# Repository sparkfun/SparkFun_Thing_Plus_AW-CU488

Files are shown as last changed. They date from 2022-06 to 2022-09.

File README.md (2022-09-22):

SparkFun AzureWave Thing Plus (AW-CU488)
========================================

SparkFun AzureWave Thing Plus (AW-CU488) (https://www.sparkfun.com/products/19957)

[*SparkFun AzureWave Thing Plus (AW-CU488) (DEV-19957)*](https://www.sparkfun.com/products/19957)

The SparkFun AzureWave Thing Plus is a Feather form-factor development board equipped with the AW-CU488. The module features the Realtek RTL8721DM integrated single-chip low-power dual-band (2.4GHz and 5GHz) wireless LAN <!--and Bluetooth&reg; Low Energy (V5.0) --> communication controller. It also consists of a dual processor core: Real-M300 CPU (ARMv8-M, Cortex-M33) and Real-M200 CPU (ARMv8-M, Cortex-M23). Connect the SparkFun AzureWave Thing Plus to the cloud to grab current weather conditions in your area, post sensor data to a server, control the lights in your next home automation project, or even calculate the Fast Fourier Transform (FFT) of an input audio signal!

Why the name? We lovingly call it the “Thing” because it's perfect for your Internet of Things project. The Thing does everything from turning on an LED to posting data with your chosen platform and can be programmed just like any microcontroller. You can even program the Thing through the Arduino IDE by installing the [Realtek Arduino core](https://github.com/ambiot/ambd_arduino). 

The board includes a USB-C connector for programming and power. Two buttons for reset and boot are also populated on the board. For those that need to go remote with their application, the board includes a 2-pin JST connector and the MCP73831 single cell, LiPo charge IC (set to a default rate of 500mA). Voltage is regulated down for the AW-CU488 with the XC6222 3.3V/700mA voltage regulator. Three status LEDs are available for power, charging, and status. Due to the size of the module, the board is slightly longer than the standard Thing Plus footprint. With the added length, we were able to break out a few more PTHs on the edge of the board for a total of 30 GPIO pins (30 Interrupts, seven Analog, 11 PWM, two UARTs, two SPI, and a single I<sup>2</sup>C). The board also includes a built-in audio CODEC with two channel analog inputs and outputs at various sample rates (8/12/16/24/32/48/.../176.4 kHz). On the back of the board are five jumpers for the LiPo charge rate, LED, auto boot circuit, and USB shielding. Finally, one Qwiic connector is populated on the board to easily add Qwiic-enabled I<sup>2</sup>C devices to your projects! 

Repository Contents
-------------------

* **/Documentation** - Datasheets, additional product information
* **/Hardware** - Eagle design files (.brd, .sch)
  * **/Production** - Production panel files (.brd)

Documentation
--------------

* **[Board Definitions](https://github.com/ambiot/ambd_arduino)** - Arduino board support files for the SparkFun AzureWave Thing Plus (AW-CU488)
* **[Hookup Guide](https://learn.sparkfun.com/tutorials/2518)** - Basic hookup guide

Product Versions
----------------

* [DEV-19957](https://www.sparkfun.com/products/19957) - Initial release

Version History
---------------
* v1.0 - Initial release

License Information
-------------------

This product is _**open source**_! 

Please review the LICENSE.md file for license information. 

If you have any questions or concerns on licensing, please contact technical support on our [SparkFun forums](https://forum.sparkfun.com/viewforum.php?f=152).

Distributed as-is; no warranty is given.

- Your friends at SparkFun.

_<COLLABORATION CREDIT>_

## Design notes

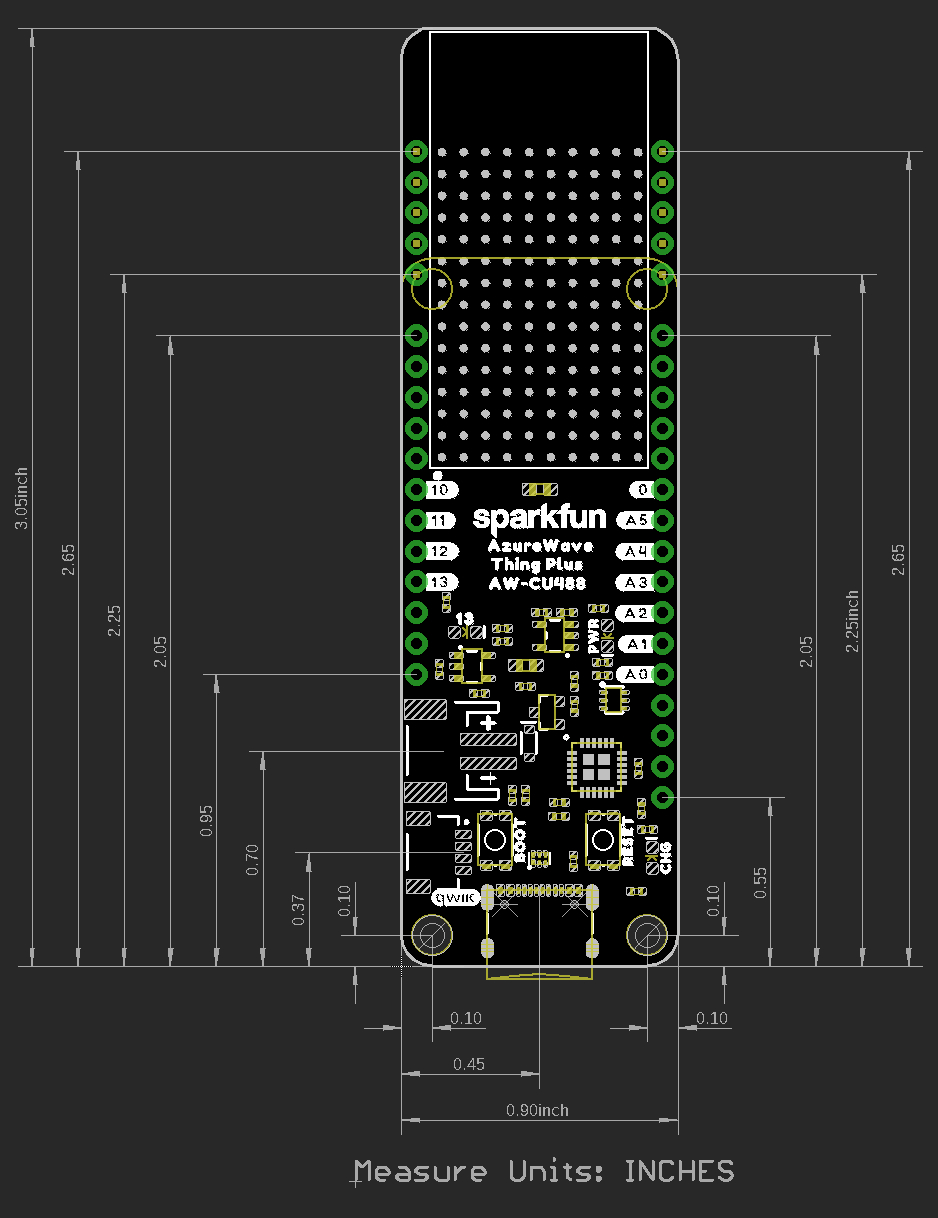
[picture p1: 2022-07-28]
Documents/SparkFun_ThingPlus_AW-CU488_DIMENSIONAL_DRAWINGS.jpg

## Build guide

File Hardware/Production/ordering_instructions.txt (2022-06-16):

panel size, 131x187mm
PCB thickness, 1.6mm
number of layers, 4
soldermask color, Red
silkscreen color, White
oz copper, 1oz
finish, HASL lead free
stencils, top
pcs per panel, 10
min trace width, 0.1524mm / 0.0060in
min drill size, 0.2540mm / 0.0100in
filename to layer stackup 1/2/3/4: GTL, GL2, GL3, GBL

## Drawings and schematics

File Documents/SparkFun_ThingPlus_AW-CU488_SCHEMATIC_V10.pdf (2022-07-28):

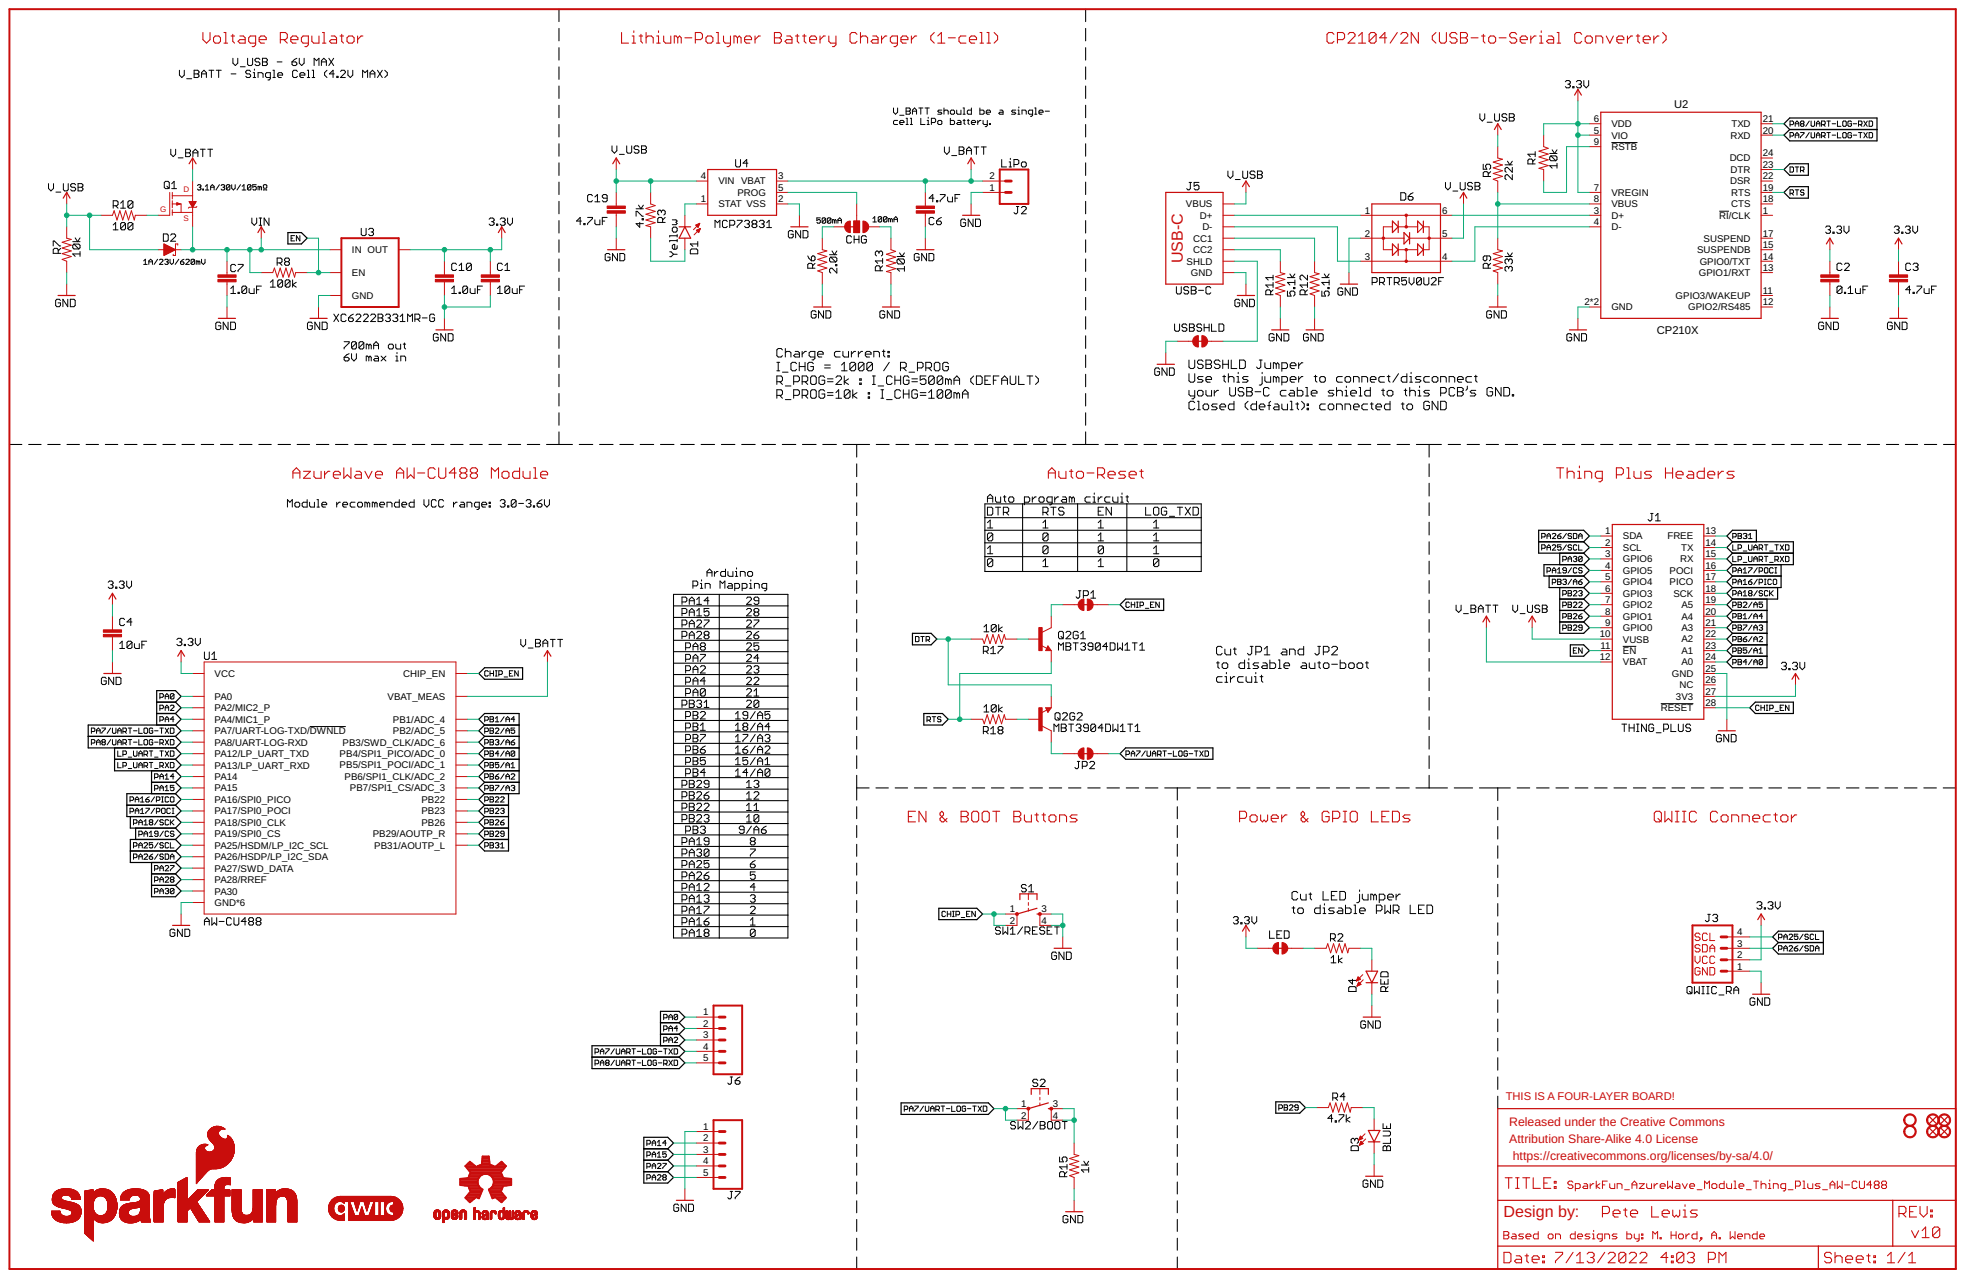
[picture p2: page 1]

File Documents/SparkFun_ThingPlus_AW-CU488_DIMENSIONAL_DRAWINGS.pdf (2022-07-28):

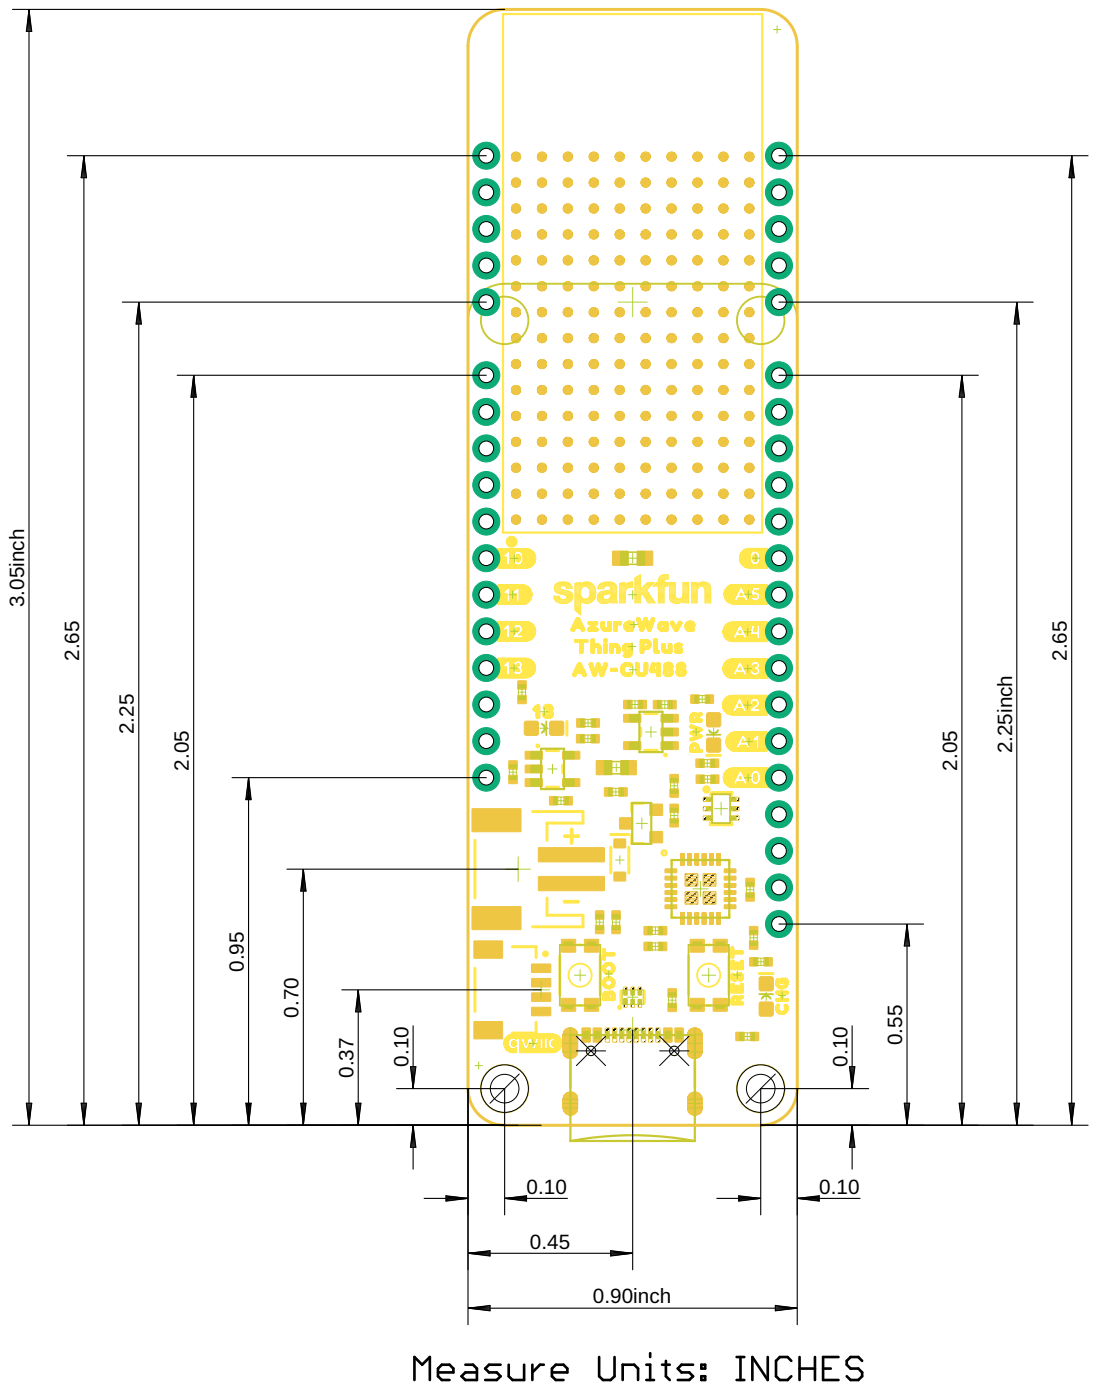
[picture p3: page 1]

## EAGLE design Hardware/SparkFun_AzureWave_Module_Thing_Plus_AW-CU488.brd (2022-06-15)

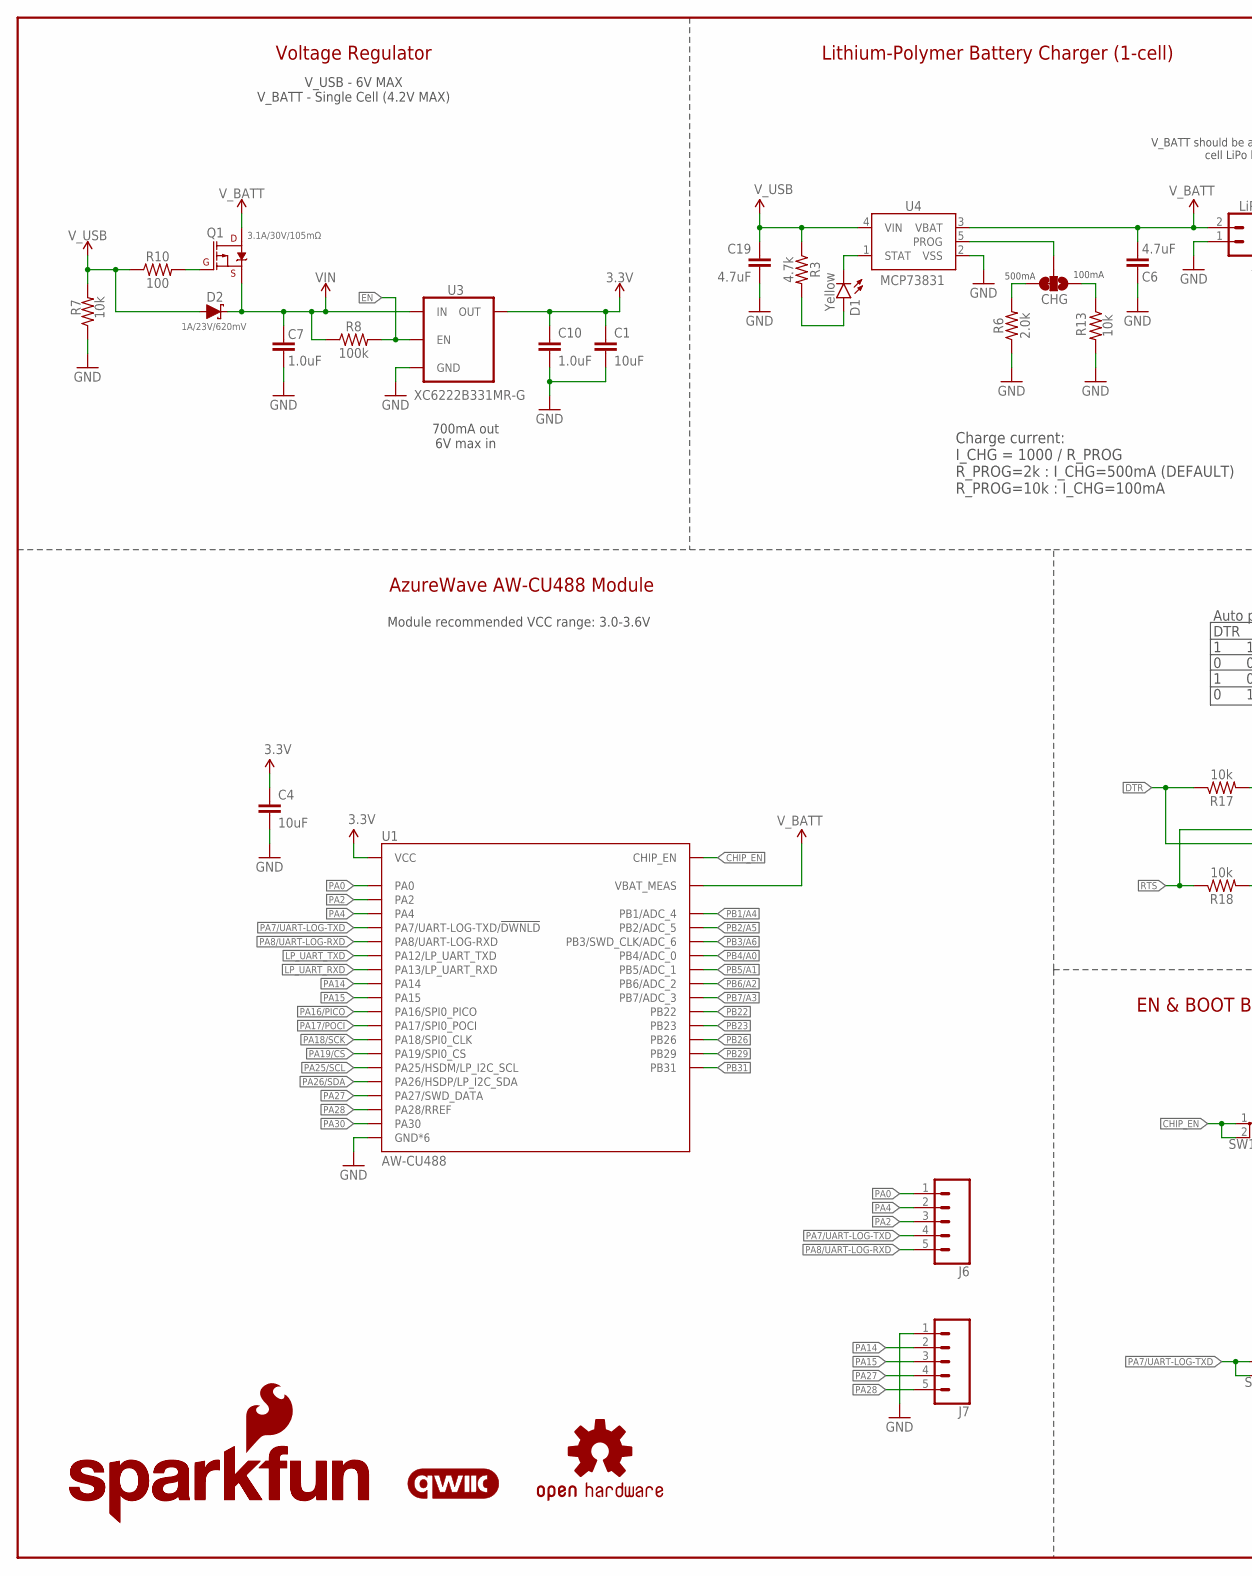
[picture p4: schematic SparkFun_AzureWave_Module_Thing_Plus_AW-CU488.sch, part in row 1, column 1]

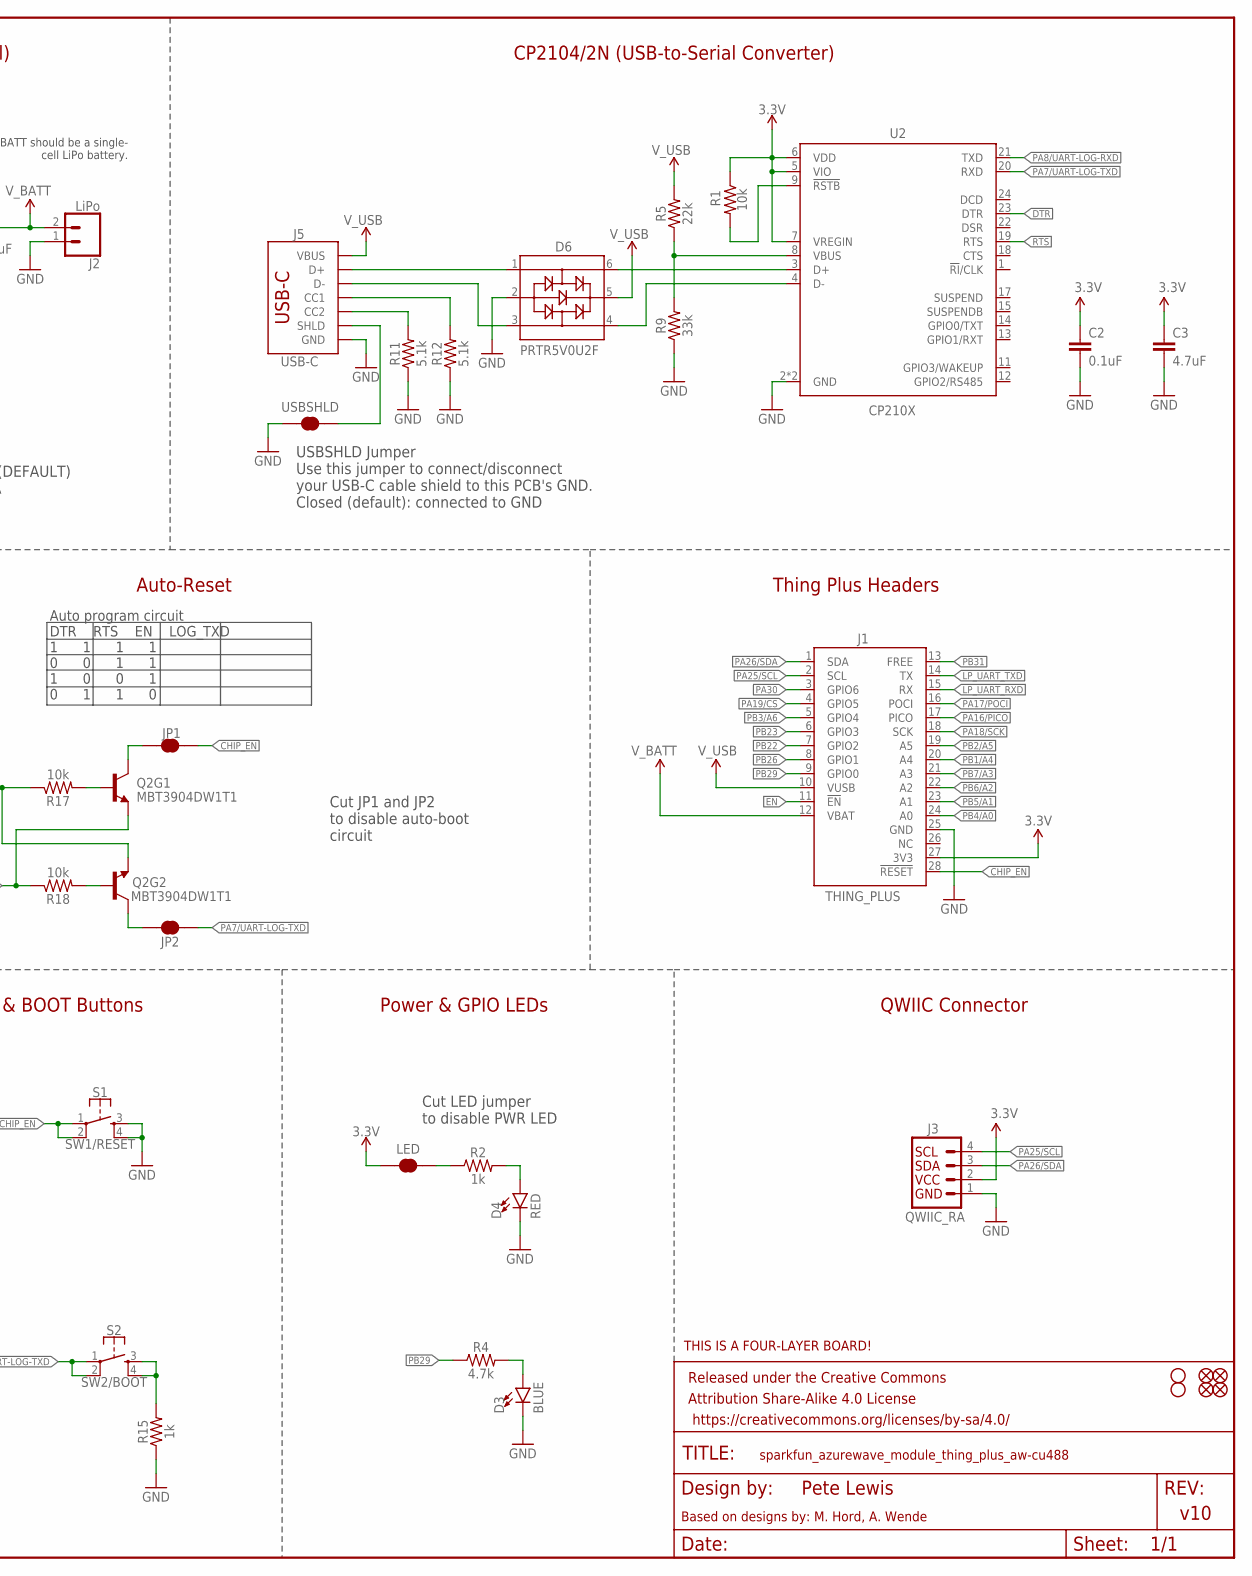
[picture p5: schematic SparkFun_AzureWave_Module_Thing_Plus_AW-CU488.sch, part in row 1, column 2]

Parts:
C1: 10uF; 0402-TIGHT
C2: 0.1uF; 0402-TIGHT
C3, C6, C19: 4.7uF; 0402-TIGHT
C4: 10uF; 0603
C7, C10: 1.0uF; 0402-TIGHT
CHG: JUMPER-SMT_3_1-NC_TRACE_SILK; SMT-JUMPER_3_1-NC_TRACE_SILK
D1: Yellow; LED-0603
D2: 1A/23V/620mV; SOD-323
D3: BLUE; LED-0603
D4: RED; LED-0603
D6: PRTR5V0U2F; SOT886
FD1, FD2, FD3, FD4: FIDUCIALUFIDUCIAL; FIDUCIAL-MICRO
FRAME1: FRAME-LEDGER; CREATIVE_COMMONS
H1, H2: STAND-OFF
J1: THING_PLUS
J2: LiPo; JST-2-SMD
J3: QWIIC_RA; JST04_1MM_RA
J5: USB-C; USB-C-16P-4LAYER-ISOLATED
J6, J7: CONN_05NO_SILK; 1X05_NO_SILK
JP1, JP2: JUMPER-SMT_2_NC_TRACE_SILK; SMT-JUMPER_2_NC_TRACE_SILK
LED: JUMPER-SMT_2_NC_TRACE_SILK; SMT-JUMPER_2_NC_TRACE_SILK
LOGO1: SFE_LOGO_NAME.1_INCH; SFE_LOGO_NAME_.1
LOGO2: OSHW-LOGOMINI; OSHW-LOGO-MINI
LOGO3: SFE_LOGO_NAME_FLAME.1_INCH; SFE_LOGO_NAME_FLAME_.1
LOGO4: FOUR_LAYER_WARNING
LOGO6: QWIIC_LOGO_4MM; QWIIC_4MM
Q1: 3.1A/30V/105mΩ; SOT23-3
Q2: MBT3904DW1T1; SC70-6
R1, R7, R13, R17, R18: 10k; 0402-TIGHT
R2, R15: 1k; 0402-TIGHT
R3, R4: 4.7k; 0402-TIGHT
R5: 22k; 0402-TIGHT
R6: 2.0k; 0603
R8: 100k; 0402-TIGHT
R9: 33k; 0402-TIGHT
R10: 100; 0402-TIGHT
R11, R12: 5.1k; 0402-TIGHT
S1: SW1/RESET; TACTILE_SWITCH_SMD_4.6X2.8MM
S2: SW2/BOOT; TACTILE_SWITCH_SMD_4.6X2.8MM
U1: AW-CU488; LGA150_AW-CU488
U2: CP210X; QFN24
U3: XC6222B331MR-G; SOT23-5
U4: MCP73831; SOT23-5
USBSHLD: JUMPER-SMT_2_NC_TRACE_SILK; SMT-JUMPER_2_NC_TRACE_SILK

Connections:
3.3V: C1.1, C2.1, C3.1, C4.1, C10.1, J1.27 (3V3), J3.2, LED.1, R1.1, U1.F1 (VCC), U2.5 (VIO), U2.6 (VDD), U2.7 (VREGIN), U3.5 (OUT)
CC1: J5.A5 (CC1), R12.2
CC2: J5.B5 (CC2), R11.2
CHG: D1.C, U4.1 (STAT)
CHIP_EN: J1.28 (!RESET), JP1.2, S1.1, S1.2, U1.K11 (CHIP_EN)
DTR: Q2.1 (E), R17.1, U2.23 (DTR)
EN: J1.11 (!EN), R8.2, U3.3 (EN)
GND: C1.2, C2.2, C3.2, C4.2, C6.2, C7.2, C10.2, C19.2, D3.C, D4.C, D6.2, J1.25 (GND), J2.1 (2), J3.1, J5.GND, J5.GND2 (GND), J7.1, R6.1, R7.1, R9.1, R11.1, R12.1, R13.2, R15.1, S1.3, S1.4, U1.A1 (GND*6), U1.A2 (GND*6), U1.A14 (GND*6), U1.A15 (GND*6), U1.B14 (GND*6), U1.B15 (GND*6), U1.C3 (GND*6), U1.C4 (GND*6), U1.C5 (GND*6), U1.C6 (GND*6), U1.C7 (GND*6), U1.C8 (GND*6), U1.C9 (GND*6), U1.C10 (GND*6), U1.C11 (GND*6), U1.C12 (GND*6), U1.C13 (GND*6), U1.C14 (GND*6), U1.C15 (GND*6), U1.D3 (GND*6), U1.D4 (GND*6), U1.D5 (GND*6), U1.D6 (GND*6), U1.D7 (GND*6), U1.D8 (GND*6), U1.D9 (GND*6), U1.D10 (GND*6), U1.D11 (GND*6), U1.D12 (GND*6), U1.D13 (GND*6), U1.D14 (GND*6), U1.D15 (GND*6), U1.E1 (GND*6), U1.E2 (GND*6), U1.E3 (GND*6), U1.E4 (GND*6), U1.E5 (GND*6), U1.E6 (GND*6), U1.E7 (GND*6), U1.E8 (GND*6), U1.E9 (GND*6), U1.E10 (GND*6), U1.E11 (GND*6), U1.E12 (GND*6), U1.E13 (GND*6), U1.E14 (GND*6), U1.E15 (GND*6), U1.F2 (GND*6), U1.F3 (GND*6), U1.F4 (GND*6), U1.F5 (GND*6), U1.F6 (GND*6), U1.F7 (GND*6), U1.F8 (GND*6), U1.F9 (GND*6), U1.F10 (GND*6), U1.F11 (GND*6), U1.F12 (GND*6), U1.F13 (GND*6), U1.F14 (GND*6), U1.F15 (GND*6), U1.G1 (GND*6), U1.G2 (GND*6), U1.G3 (GND*6), U1.G4 (GND*6), U1.G5 (GND*6), U1.G6 (GND*6), U1.G7 (GND*6), U1.G8 (GND*6), U1.G9 (GND*6), U1.G10 (GND*6), U1.G11 (GND*6), U1.G12 (GND*6), U1.G13 (GND*6), U1.G14 (GND*6), U1.G15 (GND*6), U1.H3 (GND*6), U1.H4 (GND*6), U1.H5 (GND*6), U1.H6 (GND*6), U1.H7 (GND*6), U1.H8 (GND*6), U1.H9 (GND*6), U1.H10 (GND*6), U1.H11 (GND*6), U1.H12 (GND*6), U1.H13 (GND*6), U1.H14 (GND*6), U1.H15 (GND*6), U1.J14 (GND*6), U1.J15 (GND*6), U1.K3 (GND*6), U1.K4 (GND*6), U1.K14 (GND*6), U1.K15 (GND*6), U2.2 (GND), U2.PAD (GND), U3.2 (GND), U4.2 (VSS), USBSHLD.1
LP_UART_RXD: J1.15 (RX), U1.B13 (PA13/LP_UART_RXD)
LP_UART_TXD: J1.14 (TX), U1.A13 (PA12/LP_UART_TXD)
unnamed: R1.2, U2.9 (!RSTB)
unnamed: D3.A, R4.2
unnamed: Q2.5 (B), R17.2
unnamed: R5.1, R9.2, U2.8 (VBUS)
unnamed: Q2.2 (B), R18.2
unnamed: JP1.1, Q2.3 (C)
unnamed: Q1.1 (G), R10.2
unnamed: R15.2, S2.3, S2.4
unnamed: CHG.2, U4.5 (PROG)
unnamed: JP2.1, Q2.6 (C)
unnamed: CHG.1, R13.1
unnamed: LED.2, R2.1
unnamed: CHG.3, R6.2
unnamed: D4.A, R2.2
unnamed: D6.6, U2.3 (D+)
unnamed: D6.1, J5.A6 (D+), J5.B6 (D+)
unnamed: D1.A, R3.2
unnamed: D6.4, U2.4 (D-)
unnamed: D6.3, J5.A7 (D-), J5.B7 (D-)
PA0: J6.1, U1.K8 (PA0)
PA2: J6.3, U1.K10 (PA2)
PA4: J6.2, U1.K9 (PA4)
PA7/UART-LOG-TXD: J6.4, JP2.2, S2.1, S2.2, U1.K12 (PA7/UART-LOG-TXD/!DWNLD!), U2.20 (RXD)
PA8/UART-LOG-RXD: J6.5, U1.K13 (PA8/UART-LOG-RXD), U2.21 (TXD)
PA14: J7.2, U1.A12 (PA14)
PA15: J7.3, U1.B12 (PA15)
PA16/PICO: J1.17 (PICO), U1.A11 (PA16/SPI0_PICO)
PA17/POCI: J1.16 (POCI), U1.B11 (PA17/SPI0_POCI)
PA18/SCK: J1.18 (SCK), U1.A10 (PA18/SPI0_CLK)
PA19/CS: J1.4 (GPIO5), U1.B10 (PA19/SPI0_CS)
PA25/SCL: J1.2 (SCL), J3.4, U1.A5 (PA25/HSDM/LP_I2C_SCL)
PA26/SDA: J1.1 (SDA), J3.3, U1.A6 (PA26/HSDP/LP_I2C_SDA)
PA27: J7.4, U1.A9 (PA27/SWD_DATA)
PA28: J7.5, U1.A7 (PA28/RREF)
PA30: J1.3 (GPIO6), U1.A8 (PA30)
PB1/A4: J1.20 (A4), U1.A3 (PB1/ADC_4)
PB2/A5: J1.19 (A5), U1.A4 (PB2/ADC_5)
PB3/A6: J1.5 (GPIO4), U1.B1 (PB3/SWD_CLK/ADC_6)
PB4/A0: J1.24 (A0), U1.B2 (PB4/ADC_0)
PB5/A1: J1.23 (A1), U1.C1 (PB5/ADC_1)
PB6/A2: J1.22 (A2), U1.C2 (PB6/ADC_2)
PB7/A3: J1.21 (A3), U1.D1 (PB7/ADC_3)
PB22: J1.7 (GPIO2), U1.K1 (PB22)
PB23: J1.6 (GPIO3), U1.K2 (PB23)
PB26: J1.8 (GPIO1), U1.K5 (PB26)
PB29: J1.9 (GPIO0), R4.1, U1.K6 (PB29)
PB31: J1.13 (FREE), U1.K7 (PB31)
RTS: Q2.4 (E), R18.1, U2.19 (RTS)
USB_SHLD: J5.SHLD1 (SHLD), J5.SHLD2 (SHLD), J5.SHLD3 (SHLD), J5.SHLD4 (SHLD), J5.SHLD5 (SHLD), J5.SHLD6 (SHLD), J5.SHLD7 (SHLD), J5.SHLD8 (SHLD), USBSHLD.2
VIN: C7.1, D2.C, Q1.2 (S), R8.1, U3.1 (IN)
V_BATT: C6.1, J1.12 (VBAT), J2.2 (1), Q1.3 (D), U1.D2 (VBAT_MEAS), U4.3 (VBAT)
V_USB: C19.1, D2.A, D6.5, J1.10 (VUSB), J5.VBUS1 (VBUS), J5.VBUS2 (VBUS), R3.1, R5.2, R7.2, R10.1, U4.4 (VIN)

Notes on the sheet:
CP2104/2N (USB-to-Serial Converter)
V_BATT should be a single- cell LiPo battery.
Charge current: I_CHG = 1000 / R_PROG R_PROG=2k : I_CHG=500mA (DEFAULT) R_PROG=10k : I_CHG=100mA
Voltage Regulator
Lithium-Polymer Battery Charger (1-cell)
700mA out 6V max in
AzureWave AW-CU488 Module
Thing Plus Headers
v10
QWIIC Connector
Pete Lewis
Power & GPIO LEDs
Based on designs by: M. Hord, A. Wende
V_USB - 6V MAX V_BATT - Single Cell (4.2V MAX)
100mA
500mA
Module recommended VCC range: 3.0-3.6V
EN & BOOT Buttons
Auto program circuit DTR RTS EN LOG_TXD 1 1 1 1 0 0 1 1 1 0 0 1 0 1 1 0
Auto-Reset
USBSHLD Jumper Use this jumper to connect/disconnect your USB-C cable shield to this PCB's GND. Closed (default): connected to GND
Cut JP1 and JP2 to disable auto-boot circuit
Cut LED jumper to disable PWR LED

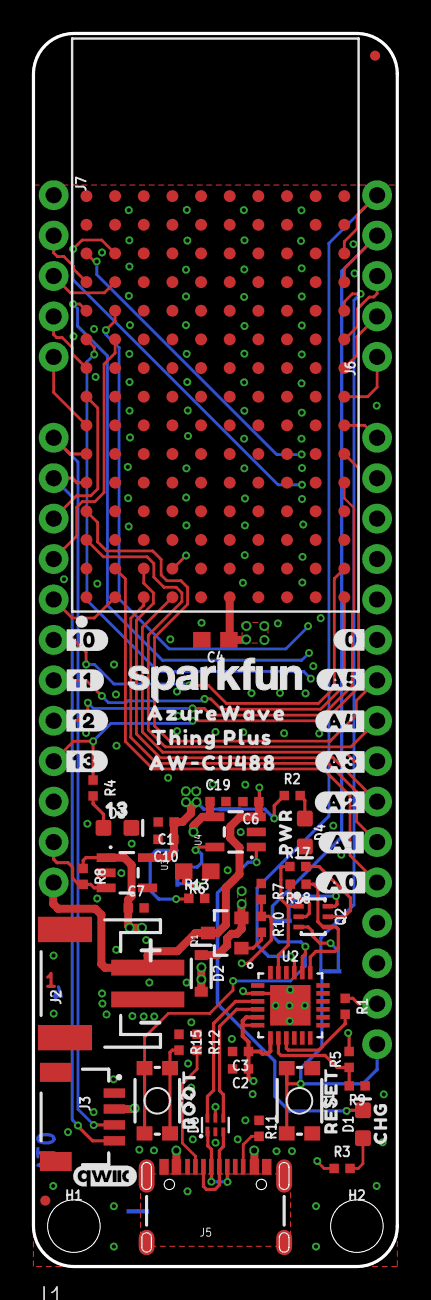
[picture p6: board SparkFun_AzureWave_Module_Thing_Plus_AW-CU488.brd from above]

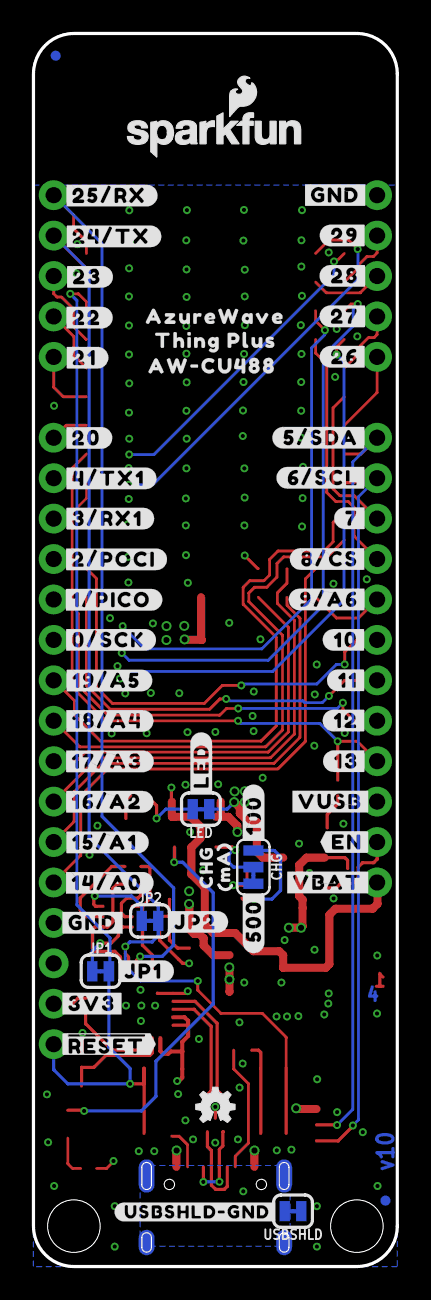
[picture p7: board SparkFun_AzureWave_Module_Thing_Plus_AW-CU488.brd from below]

Board: 4 copper layers, 22.9 x 77.5 mm, 128 parts (57 on the bottom side), 62 nets.

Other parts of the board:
U$1: #10#30
U$2: BOOT0
U$3, U$78: CHG0
U$4: #500#0
U$5: #11#30
U$6, U$8: AZUREWAVE0
U$7: 1330
U$9, U$27: AW#CU488_0
U$10, U$62: THING_PLUS_0
U$11: MA0
U$12: #12#30
U$14: #13#30
U$15: #JP1#1
U$16: #0#1
U$18: #A0#30
U$19: #JP2#4
U$20: #USBSHLD#GND#3
U$23: PWR0
U$29: #LED#0
U$32, U$86: #GND#0
U$41: #VUSB#0
U$42: #VBAT#0
U$43: #EN#0
U$45: #3V3#0
U$46: ##RESET##0
U$48: #4#TX1#14
U$49: #3#RX1#14
U$50: #2#POCI#14
U$53: #A1#6
U$54: #A2#6
U$55: #A3#6
U$56: #A4#6
U$57: #A5#6
U$59: ORDERING_INSTRUCTIONS
U$60: #100#0
U$64: #1#PICO#14
U$67: #13#14
U$68: #12#14
U$69: #11#14
U$70: #10#14
U$71: #9#A6#14
U$72: #8#CS#14
U$73: #7#14
U$74: #6#SCL#14
U$75: #5#SDA#14
U$76: #0#SCK#14
U$77: #14#A0#15
U$79: RESET0
U$80: #15#A1#15
U$81: #16#A2#16
U$82: #17#A3#17
U$83: #18#A4#18
U$84: #19#A5#19
U$85: #20#20
U$87: #21#21
U$88: #22#22
U$89: #23#23
U$90: #24#TX#24
U$91: #25#RX#25
U$92: #26#26
U$93: #27#27
U$94: #28#28
U$95: #29#29

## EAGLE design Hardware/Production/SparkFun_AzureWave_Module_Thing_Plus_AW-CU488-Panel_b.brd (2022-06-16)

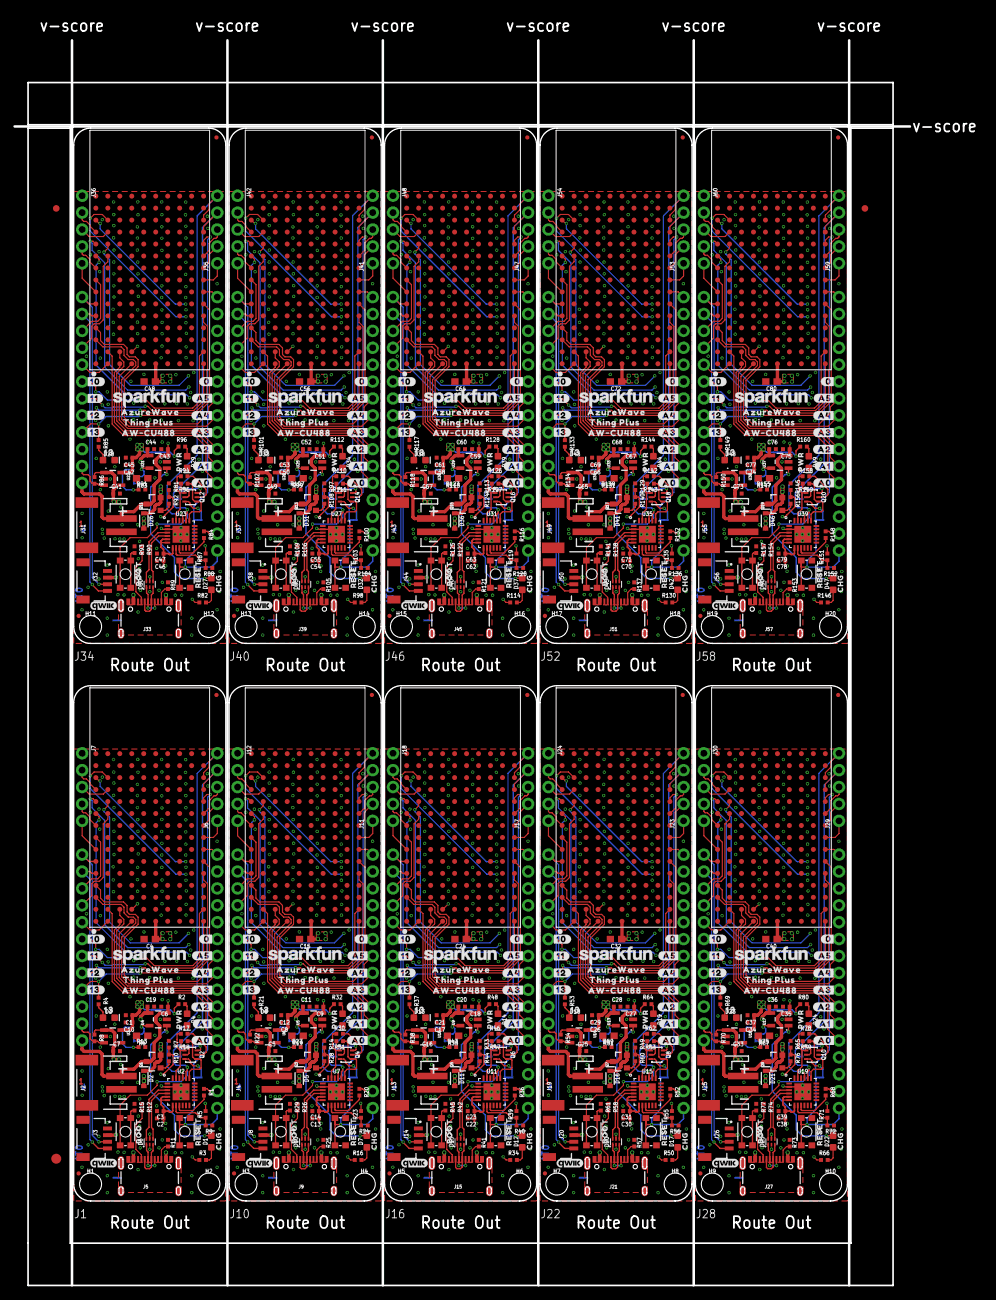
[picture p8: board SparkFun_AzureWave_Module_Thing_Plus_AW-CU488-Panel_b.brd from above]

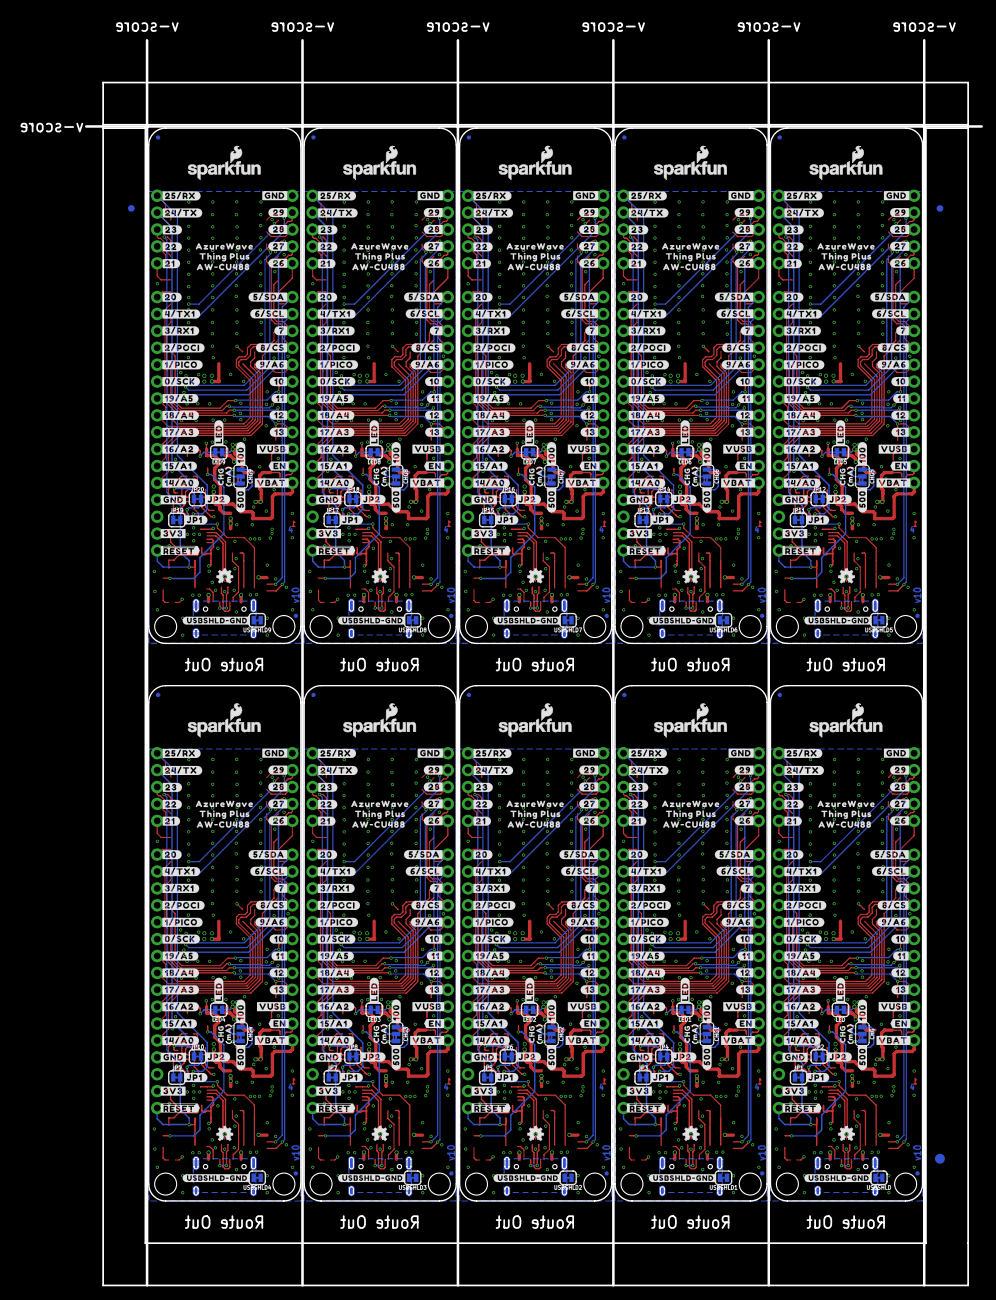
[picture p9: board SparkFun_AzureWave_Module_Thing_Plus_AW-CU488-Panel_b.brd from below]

Board: 4 copper layers, 134.6 x 187.2 mm, 1276 parts (573 on the bottom side), 620 nets.

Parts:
C1, C12, C21, C29, C37, C45, C53, C61, C69, C77: 10uF; 0402-TIGHT
C2, C13, C22, C30, C38, C46, C54, C62, C70, C78: 0.1uF; 0402-TIGHT
C3, C6, C9, C11, C14, C18, C19, C20, C23, C27, C28, C31, C35, C36, C39, C43, C44, C47, C51, C52, C55, C59, C60, C63, C67, C68, C71, C75, C76, C79: 4.7uF; 0402-TIGHT
C4, C15, C24, C32, C40, C48, C56, C64, C72, C80: 10uF; 0603
C5, C7, C8, C10, C16, C17, C25, C26, C33, C34, C41, C42, C49, C50, C57, C58, C65, C66, C73, C74: 1.0uF; 0402-TIGHT
CHG, CHG1, CHG2, CHG3, CHG4, CHG5, CHG6, CHG7, CHG8, CHG9: SMT-JUMPER_3_1-NC_TRACE_SILK
D1, D7, D12, D17, D22, D27, D32, D37, D42, D47: Yellow; LED-0603
D2, D5, D11, D16, D21, D26, D31, D36, D41, D46: 1A/23V/620mV; SOD-323
D3, D8, D13, D18, D23, D28, D33, D38, D43, D48: BLUE; LED-0603
D4, D9, D14, D19, D24, D29, D34, D39, D44, D49: RED; LED-0603
D6, D10, D15, D20, D25, D30, D35, D40, D45, D50: PRTR5V0U2F; SOT886
E$1, E$2, E$3, E$4: FIDUCIAL-1X2
E$5, E$6: FIDUCIAL-1.5X3
FD1, FD2, FD3, FD4, FD5, FD6, FD7, FD8, FD9, FD10, FD11, FD12, FD13, FD14, FD15, FD16, FD17, FD18, FD19, FD20, FD21, FD22, FD23, FD24, FD25, FD26, FD27, FD28, FD29, FD30, FD31, FD32, FD33, FD34, FD35, FD36, FD37, FD38, FD39, FD40: FIDUCIALUFIDUCIAL; FIDUCIAL-MICRO
H1, H2, H3, H4, H5, H6, H7, H8, H9, H10, H11, H12, H13, H14, H15, H16, H17, H18, H19, H20: STAND-OFF
J1, J10, J16, J22, J28, J34, J40, J46, J52, J58: THING_PLUS
J2, J4, J13, J19, J25, J31, J37, J43, J49, J55: LiPo; JST-2-SMD
J3, J8, J14, J20, J26, J32, J38, J44, J50, J56: QWIIC_RA; JST04_1MM_RA
J5, J9, J15, J21, J27, J33, J39, J45, J51, J57: USB-C; USB-C-16P-4LAYER-ISOLATED
J6, J7, J11, J12, J17, J18, J23, J24, J29, J30, J35, J36, J41, J42, J47, J48, J53, J54, J59, J60: 1X05_NO_SILK
JP1, JP2, JP3, JP4, JP5, JP6, JP7, JP8, JP9, JP10, JP11, JP12, JP13, JP14, JP15, JP16, JP17, JP18, JP19, JP20: SMT-JUMPER_2_NC_TRACE_SILK
LED, LED1, LED2, LED3, LED4, LED5, LED6, LED7, LED8, LED9: SMT-JUMPER_2_NC_TRACE_SILK
LOGO1, LOGO9, LOGO14, LOGO19, LOGO24, LOGO29, LOGO34, LOGO39, LOGO44, LOGO49: SFE_LOGO_NAME.1_INCH; SFE_LOGO_NAME_.1
LOGO2, LOGO5, LOGO11, LOGO16, LOGO21, LOGO26, LOGO31, LOGO36, LOGO41, LOGO46: OSHW-LOGOMINI; OSHW-LOGO-MINI
LOGO3, LOGO10, LOGO15, LOGO20, LOGO25, LOGO30, LOGO35, LOGO40, LOGO45, LOGO50: SFE_LOGO_NAME_FLAME.1_INCH; SFE_LOGO_NAME_FLAME_.1
LOGO4, LOGO7, LOGO12, LOGO17, LOGO22, LOGO27, LOGO32, LOGO37, LOGO42, LOGO47: FOUR_LAYER_WARNING
LOGO6, LOGO8, LOGO13, LOGO18, LOGO23, LOGO28, LOGO33, LOGO38, LOGO43, LOGO48: QWIIC_LOGO_4MM; QWIIC_4MM
Q1, Q3, Q5, Q7, Q9, Q11, Q13, Q15, Q17, Q19: 3.1A/30V/105mΩ; SOT23-3
Q2, Q4, Q6, Q8, Q10, Q12, Q14, Q16, Q18, Q20: MBT3904DW1T1; SC70-6
R1, R7, R13, R14, R17, R18, R20, R27, R30, R31, R33, R36, R43, R46, R47, R49, R52, R59, R62, R63, R65, R68, R75, R78, R79, R81, R84, R91, R94, R95, R97, R100, R107, R110, R111, R113, R116, R123, R126, R127, R129, R132, R139, R142, R143, R145, R148, R155, R158, R159: 10k; 0402-TIGHT
R2, R15, R29, R32, R45, R48, R61, R64, R77, R80, R93, R96, R109, R112, R125, R128, R141, R144, R157, R160: 1k; 0402-TIGHT
R3, R4, R16, R21, R34, R37, R50, R53, R66, R69, R82, R85, R98, R101, R114, R117, R130, R133, R146, R149: 4.7k; 0402-TIGHT
R5, R23, R39, R55, R71, R87, R103, R119, R135, R151: 22k; 0402-TIGHT
R6, R19, R35, R51, R67, R83, R99, R115, R131, R147: 2.0k; 0603
R8, R22, R38, R54, R70, R86, R102, R118, R134, R150: 100k; 0402-TIGHT
R9, R24, R40, R56, R72, R88, R104, R120, R136, R152: 33k; 0402-TIGHT
R10, R28, R44, R60, R76, R92, R108, R124, R140, R156: 100; 0402-TIGHT
R11, R12, R25, R26, R41, R42, R57, R58, R73, R74, R89, R90, R105, R106, R121, R122, R137, R138, R153, R154: 5.1k; 0402-TIGHT
S1, S3, S5, S7, S9, S11, S13, S15, S17, S19: SW1/RESET; TACTILE_SWITCH_SMD_4.6X2.8MM
S2, S4, S6, S8, S10, S12, S14, S16, S18, S20: SW2/BOOT; TACTILE_SWITCH_SMD_4.6X2.8MM
U1, U8, U12, U16, U20, U24, U28, U32, U36, U40: AW-CU488; LGA150_AW-CU488
U2, U7, U11, U15, U19, U23, U27, U31, U35, U39: CP210X; QFN24
U3, U6, U10, U14, U18, U22, U26, U30, U34, U38: XC6222B331MR-G; SOT23-5
U4, U5, U9, U13, U17, U21, U25, U29, U33, U37: MCP73831; SOT23-5
U$1, U$129, U$197, U$265, U$333, U$401, U$469, U$537, U$605, U$673: #10#30
U$2, U$38, U$152, U$220, U$288, U$356, U$424, U$492, U$560, U$628: BOOT0
U$3, U$17, U$31, U$78, U$138, U$146, U$206, U$214, U$274, U$282, U$342, U$350, U$410, U$418, U$478, U$486, U$546, U$554, U$614, U$622: CHG0
U$4, U$35, U$149, U$217, U$285, U$353, U$421, U$489, U$557, U$625: #500#0
U$5, U$130, U$198, U$266, U$334, U$402, U$470, U$538, U$606, U$674: #11#30
U$6, U$8, U$39, U$40, U$153, U$154, U$221, U$222, U$289, U$290, U$357, U$358, U$425, U$426, U$493, U$494, U$561, U$562, U$629, U$630: AZUREWAVE0
U$7, U$133, U$201, U$269, U$337, U$405, U$473, U$541, U$609, U$677: 1330
U$9, U$27, U$37, U$44, U$151, U$155, U$219, U$223, U$287, U$291, U$355, U$359, U$423, U$427, U$491, U$495, U$559, U$563, U$627, U$631: AW#CU488_0
U$10, U$36, U$47, U$62, U$150, U$156, U$218, U$224, U$286, U$292, U$354, U$360, U$422, U$428, U$490, U$496, U$558, U$564, U$626, U$632: THING_PLUS_0
U$11, U$33, U$147, U$215, U$283, U$351, U$419, U$487, U$555, U$623: MA0
U$12, U$131, U$199, U$267, U$335, U$403, U$471, U$539, U$607, U$675: #12#30
U$13, U$59, U$137, U$205, U$273, U$341, U$409, U$477, U$545, U$613: ORDERING_INSTRUCTIONS
U$14, U$132, U$200, U$268, U$336, U$404, U$472, U$540, U$608, U$676: #13#30
U$15, U$135, U$203, U$271, U$339, U$407, U$475, U$543, U$611, U$679: #JP1#1
U$16, U$134, U$202, U$270, U$338, U$406, U$474, U$542, U$610, U$678: #0#1
U$18, U$65, U$162, U$230, U$298, U$366, U$434, U$502, U$570, U$638: #A0#30
U$19, U$136, U$204, U$272, U$340, U$408, U$476, U$544, U$612, U$680: #JP2#4
U$20, U$66, U$163, U$231, U$299, U$367, U$435, U$503, U$571, U$639: #USBSHLD#GND#3
U$21, U$79, U$139, U$207, U$275, U$343, U$411, U$479, U$547, U$615: RESET0
U$22, U$41, U$140, U$208, U$276, U$344, U$412, U$480, U$548, U$616: #VUSB#0
U$23, U$96, U$164, U$232, U$300, U$368, U$436, U$504, U$572, U$640: PWR0
U$24, U$42, U$141, U$209, U$277, U$345, U$413, U$481, U$549, U$617: #VBAT#0
U$25, U$43, U$142, U$210, U$278, U$346, U$414, U$482, U$550, U$618: #EN#0
U$26, U$32, U$86, U$119, U$143, U$187, U$211, U$255, U$279, U$323, U$347, U$391, U$415, U$459, U$483, U$527, U$551, U$595, U$619, U$663: #GND#0
U$28, U$45, U$144, U$212, U$280, U$348, U$416, U$484, U$552, U$620: #3V3#0
U$29, U$97, U$165, U$233, U$301, U$369, U$437, U$505, U$573, U$641: #LED#0
U$30, U$46, U$145, U$213, U$281, U$349, U$417, U$485, U$553, U$621: ##RESET##0
U$34, U$60, U$148, U$216, U$284, U$352, U$420, U$488, U$556, U$624: #100#0
U$48, U$107, U$175, U$243, U$311, U$379, U$447, U$515, U$583, U$651: #4#TX1#14
U$49, U$108, U$176, U$244, U$312, U$380, U$448, U$516, U$584, U$652: #3#RX1#14
U$50, U$109, U$177, U$245, U$313, U$381, U$449, U$517, U$585, U$653: #2#POCI#14
U$51, U$53, U$157, U$225, U$293, U$361, U$429, U$497, U$565, U$633: #A1#6
U$52, U$54, U$158, U$226, U$294, U$362, U$430, U$498, U$566, U$634: #A2#6
U$55, U$58, U$159, U$227, U$295, U$363, U$431, U$499, U$567, U$635: #A3#6
U$56, U$61, U$160, U$228, U$296, U$364, U$432, U$500, U$568, U$636: #A4#6
U$57, U$63, U$161, U$229, U$297, U$365, U$433, U$501, U$569, U$637: #A5#6
U$64, U$110, U$178, U$246, U$314, U$382, U$450, U$518, U$586, U$654: #1#PICO#14
U$67, U$98, U$166, U$234, U$302, U$370, U$438, U$506, U$574, U$642: #13#14
U$68, U$99, U$167, U$235, U$303, U$371, U$439, U$507, U$575, U$643: #12#14
U$69, U$100, U$168, U$236, U$304, U$372, U$440, U$508, U$576, U$644: #11#14
U$70, U$101, U$169, U$237, U$305, U$373, U$441, U$509, U$577, U$645: #10#14
U$71, U$102, U$170, U$238, U$306, U$374, U$442, U$510, U$578, U$646: #9#A6#14
U$72, U$103, U$171, U$239, U$307, U$375, U$443, U$511, U$579, U$647: #8#CS#14
U$73, U$104, U$172, U$240, U$308, U$376, U$444, U$512, U$580, U$648: #7#14
U$74, U$105, U$173, U$241, U$309, U$377, U$445, U$513, U$581, U$649: #6#SCL#14
U$75, U$106, U$174, U$242, U$310, U$378, U$446, U$514, U$582, U$650: #5#SDA#14
U$76, U$111, U$179, U$247, U$315, U$383, U$451, U$519, U$587, U$655: #0#SCK#14
U$77, U$112, U$180, U$248, U$316, U$384, U$452, U$520, U$588, U$656: #14#A0#15
U$80, U$113, U$181, U$249, U$317, U$385, U$453, U$521, U$589, U$657: #15#A1#15
U$81, U$114, U$182, U$250, U$318, U$386, U$454, U$522, U$590, U$658: #16#A2#16
U$82, U$115, U$183, U$251, U$319, U$387, U$455, U$523, U$591, U$659: #17#A3#17
U$83, U$116, U$184, U$252, U$320, U$388, U$456, U$524, U$592, U$660: #18#A4#18
U$84, U$117, U$185, U$253, U$321, U$389, U$457, U$525, U$593, U$661: #19#A5#19
U$85, U$118, U$186, U$254, U$322, U$390, U$458, U$526, U$594, U$662: #20#20
U$87, U$120, U$188, U$256, U$324, U$392, U$460, U$528, U$596, U$664: #21#21
U$88, U$121, U$189, U$257, U$325, U$393, U$461, U$529, U$597, U$665: #22#22
U$89, U$122, U$190, U$258, U$326, U$394, U$462, U$530, U$598, U$666: #23#23
U$90, U$123, U$191, U$259, U$327, U$395, U$463, U$531, U$599, U$667: #24#TX#24
U$91, U$124, U$192, U$260, U$328, U$396, U$464, U$532, U$600, U$668: #25#RX#25
U$92, U$125, U$193, U$261, U$329, U$397, U$465, U$533, U$601, U$669: #26#26
U$93, U$126, U$194, U$262, U$330, U$398, U$466, U$534, U$602, U$670: #27#27
U$94, U$127, U$195, U$263, U$331, U$399, U$467, U$535, U$603, U$671: #28#28
U$95, U$128, U$196, U$264, U$332, U$400, U$468, U$536, U$604, U$672: #29#29
USBSHLD, USBSHLD1, USBSHLD2, USBSHLD3, USBSHLD4, USBSHLD5, USBSHLD6, USBSHLD7, USBSHLD8, USBSHLD9: SMT-JUMPER_2_NC_TRACE_SILK

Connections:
3.3V: C1.1, C2.1, C3.1, C4.1, C10.1, J1.27, J3.2, LED.1, R1.1, U1.F1, U2.5, U2.6, U2.7, U3.5
3.3V1: C8.1, C12.1, C13.1, C14.1, C15.1, J8.2, J10.27, LED1.1, R20.1, U6.5, U7.5, U7.6, U7.7, U8.F1
3.3V2: C17.1, C21.1, C22.1, C23.1, C24.1, J14.2, J16.27, LED2.1, R36.1, U10.5, U11.5, U11.6, U11.7, U12.F1
3.3V3: C26.1, C29.1, C30.1, C31.1, C32.1, J20.2, J22.27, LED3.1, R52.1, U14.5, U15.5, U15.6, U15.7, U16.F1
3.3V4: C34.1, C37.1, C38.1, C39.1, C40.1, J26.2, J28.27, LED4.1, R68.1, U18.5, U19.5, U19.6, U19.7, U20.F1
3.3V5: C42.1, C45.1, C46.1, C47.1, C48.1, J32.2, J34.27, LED5.1, R84.1, U22.5, U23.5, U23.6, U23.7, U24.F1
3.3V6: C50.1, C53.1, C54.1, C55.1, C56.1, J38.2, J40.27, LED6.1, R100.1, U26.5, U27.5, U27.6, U27.7, U28.F1
3.3V7: C58.1, C61.1, C62.1, C63.1, C64.1, J44.2, J46.27, LED7.1, R116.1, U30.5, U31.5, U31.6, U31.7, U32.F1
3.3V8: C66.1, C69.1, C70.1, C71.1, C72.1, J50.2, J52.27, LED8.1, R132.1, U34.5, U35.5, U35.6, U35.7, U36.F1
3.3V9: C74.1, C77.1, C78.1, C79.1, C80.1, J56.2, J58.27, LED9.1, R148.1, U38.5, U39.5, U39.6, U39.7, U40.F1
CC1: J5.A5, R12.2
CC2: J5.B5, R11.2
CC3: J9.B5, R25.2
CC4: J9.A5, R26.2
CC5: J15.B5, R41.2
CC6: J15.A5, R42.2
CC7: J21.B5, R57.2
CC8: J21.A5, R58.2
CC9: J27.B5, R73.2
CC10: J27.A5, R74.2
CC11: J33.B5, R89.2
CC12: J33.A5, R90.2
CC13: J39.B5, R105.2
CC14: J39.A5, R106.2
CC15: J45.B5, R121.2
CC16: J45.A5, R122.2
CC17: J51.B5, R137.2
CC18: J51.A5, R138.2
CC19: J57.B5, R153.2
CC20: J57.A5, R154.2
CHG: D1.C, U4.1
CHG1: D7.C, U5.1
CHG2: D12.C, U9.1
CHG3: D17.C, U13.1
CHG4: D22.C, U17.1
CHG5: D27.C, U21.1
CHG6: D32.C, U25.1
CHG7: D37.C, U29.1
CHG8: D42.C, U33.1
CHG9: D47.C, U37.1
CHIP_EN: J1.28, JP1.2, S1.1, S1.2, U1.K11
CHIP_EN1: J10.28, JP3.2, S3.1, S3.2, U8.K11
CHIP_EN2: J16.28, JP5.2, S5.1, S5.2, U12.K11
CHIP_EN3: J22.28, JP7.2, S7.1, S7.2, U16.K11
CHIP_EN4: J28.28, JP9.2, S9.1, S9.2, U20.K11
CHIP_EN5: J34.28, JP11.2, S11.1, S11.2, U24.K11
CHIP_EN6: J40.28, JP13.2, S13.1, S13.2, U28.K11
CHIP_EN7: J46.28, JP15.2, S15.1, S15.2, U32.K11
CHIP_EN8: J52.28, JP17.2, S17.1, S17.2, U36.K11
CHIP_EN9: J58.28, JP19.2, S19.1, S19.2, U40.K11
DTR: Q2.1, R17.1, U2.23
DTR1: Q4.1, R30.1, U7.23
DTR2: Q6.1, R46.1, U11.23
DTR3: Q8.1, R62.1, U15.23
DTR4: Q10.1, R78.1, U19.23
DTR5: Q12.1, R94.1, U23.23
DTR6: Q14.1, R110.1, U27.23
DTR7: Q16.1, R126.1, U31.23
DTR8: Q18.1, R142.1, U35.23
DTR9: Q20.1, R158.1, U39.23
EN: J1.11, R8.2, U3.3
EN1: J10.11, R22.2, U6.3
EN2: J16.11, R38.2, U10.3
EN3: J22.11, R54.2, U14.3
EN4: J28.11, R70.2, U18.3
EN5: J34.11, R86.2, U22.3
EN6: J40.11, R102.2, U26.3
EN7: J46.11, R118.2, U30.3
EN8: J52.11, R134.2, U34.3
EN9: J58.11, R150.2, U38.3
GND: C1.2, C2.2, C3.2, C4.2, C6.2, C7.2, C10.2, C19.2, D3.C, D4.C, D6.2, J1.25, J2.1, J3.1, J5.GND, J5.GND2, J7.1, R6.1, R7.1, R9.1, R11.1, R12.1, R13.2, R15.1, S1.3, S1.4, U1.A1, U1.A2, U1.A14, U1.A15, U1.B14, U1.B15, U1.C3, U1.C4, U1.C5, U1.C6, U1.C7, U1.C8, U1.C9, U1.C10, U1.C11, U1.C12, U1.C13, U1.C14, U1.C15, U1.D3, U1.D4, U1.D5, U1.D6, U1.D7, U1.D8, U1.D9, U1.D10, U1.D11, U1.D12, U1.D13, U1.D14, U1.D15, U1.E1, U1.E2, U1.E3, U1.E4, U1.E5, U1.E6, U1.E7, U1.E8, U1.E9, U1.E10, U1.E11, U1.E12, U1.E13, U1.E14, U1.E15, U1.F2, U1.F3, U1.F4, U1.F5, U1.F6, U1.F7, U1.F8, U1.F9, U1.F10, U1.F11, U1.F12, U1.F13, U1.F14, U1.F15, U1.G1, U1.G2, U1.G3, U1.G4, U1.G5, U1.G6, U1.G7, U1.G8, U1.G9, U1.G10, U1.G11, U1.G12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
GND1: C5.2, C8.2, C9.2, C11.2, C12.2, C13.2, C14.2, C15.2, D8.C, D9.C, D10.2, J4.1, J8.1, J9.GND, J9.GND2, J10.25, J12.1, R14.1, R19.1, R24.1, R25.1, R26.1, R27.2, R29.1, S3.3, S3.4, U5.2, U6.2, U7.2, U7.PAD, U8.A1, U8.A2, U8.A14, U8.A15, U8.B14, U8.B15, U8.C3, U8.C4, U8.C5, U8.C6, U8.C7, U8.C8, U8.C9, U8.C10, U8.C11, U8.C12, U8.C13, U8.C14, U8.C15, U8.D3, U8.D4, U8.D5, U8.D6, U8.D7, U8.D8, U8.D9, U8.D10, U8.D11, U8.D12, U8.D13, U8.D14, U8.D15, U8.E1, U8.E2, U8.E3, U8.E4, U8.E5, U8.E6, U8.E7, U8.E8, U8.E9, U8.E10, U8.E11, U8.E12, U8.E13, U8.E14, U8.E15, U8.F2, U8.F3, U8.F4, U8.F5, U8.F6, U8.F7, U8.F8, U8.F9, U8.F10, U8.F11, U8.F12, U8.F13, U8.F14, U8.F15, U8.G1, U8.G2, U8.G3, U8.G4, U8.G5, U8.G6, U8.G7, U8.G8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
GND2: C16.2, C17.2, C18.2, C20.2, C21.2, C22.2, C23.2, C24.2, D13.C, D14.C, D15.2, J13.1, J14.1, J15.GND, J15.GND2, J16.25, J18.1, R33.1, R35.1, R40.1, R41.1, R42.1, R43.2, R45.1, S5.3, S5.4, U9.2, U10.2, U11.2, U11.PAD, U12.A1, U12.A2, U12.A14, U12.A15, U12.B14, U12.B15, U12.C3, U12.C4, U12.C5, U12.C6, U12.C7, U12.C8, U12.C9, U12.C10, U12.C11, U12.C12, U12.C13, U12.C14, U12.C15, U12.D3, U12.D4, U12.D5, U12.D6, U12.D7, U12.D8, U12.D9, U12.D10, U12.D11, U12.D12, U12.D13, U12.D14, U12.D15, U12.E1, U12.E2, U12.E3, U12.E4, U12.E5, U12.E6, U12.E7, U12.E8, U12.E9, U12.E10, U12.E11, U12.E12, U12.E13, U12.E14, U12.E15, U12.F2, U12.F3, U12.F4, U12.F5, U12.F6, U12.F7, U12.F8, U12.F9, U12.F10, U12.F11, U12.F12, U12.F13, U12.F14, U12.F15, U12.G1, U12.G2, U12.G3, U12.G4, U12.G5, U12.G6, U12.G7, U12.G8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
GND3: C25.2, C26.2, C27.2, C28.2, C29.2, C30.2, C31.2, C32.2, D18.C, D19.C, D20.2, J19.1, J20.1, J21.GND, J21.GND2, J22.25, J24.1, R49.1, R51.1, R56.1, R57.1, R58.1, R59.2, R61.1, S7.3, S7.4, U13.2, U14.2, U15.2, U15.PAD, U16.A1, U16.A2, U16.A14, U16.A15, U16.B14, U16.B15, U16.C3, U16.C4, U16.C5, U16.C6, U16.C7, U16.C8, U16.C9, U16.C10, U16.C11, U16.C12, U16.C13, U16.C14, U16.C15, U16.D3, U16.D4, U16.D5, U16.D6, U16.D7, U16.D8, U16.D9, U16.D10, U16.D11, U16.D12, U16.D13, U16.D14, U16.D15, U16.E1, U16.E2, U16.E3, U16.E4, U16.E5, U16.E6, U16.E7, U16.E8, U16.E9, U16.E10, U16.E11, U16.E12, U16.E13, U16.E14, U16.E15, U16.F2, U16.F3, U16.F4, U16.F5, U16.F6, U16.F7, U16.F8, U16.F9, U16.F10, U16.F11, U16.F12, U16.F13, U16.F14, U16.F15, U16.G1, U16.G2, U16.G3, U16.G4, U16.G5, U16.G6, U16.G7, U16.G8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
GND4: C33.2, C34.2, C35.2, C36.2, C37.2, C38.2, C39.2, C40.2, D23.C, D24.C, D25.2, J25.1, J26.1, J27.GND, J27.GND2, J28.25, J30.1, R65.1, R67.1, R72.1, R73.1, R74.1, R75.2, R77.1, S9.3, S9.4, U17.2, U18.2, U19.2, U19.PAD, U20.A1, U20.A2, U20.A14, U20.A15, U20.B14, U20.B15, U20.C3, U20.C4, U20.C5, U20.C6, U20.C7, U20.C8, U20.C9, U20.C10, U20.C11, U20.C12, U20.C13, U20.C14, U20.C15, U20.D3, U20.D4, U20.D5, U20.D6, U20.D7, U20.D8, U20.D9, U20.D10, U20.D11, U20.D12, U20.D13, U20.D14, U20.D15, U20.E1, U20.E2, U20.E3, U20.E4, U20.E5, U20.E6, U20.E7, U20.E8, U20.E9, U20.E10, U20.E11, U20.E12, U20.E13, U20.E14, U20.E15, U20.F2, U20.F3, U20.F4, U20.F5, U20.F6, U20.F7, U20.F8, U20.F9, U20.F10, U20.F11, U20.F12, U20.F13, U20.F14, U20.F15, U20.G1, U20.G2, U20.G3, U20.G4, U20.G5, U20.G6, U20.G7, U20.G8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
GND5: C41.2, C42.2, C43.2, C44.2, C45.2, C46.2, C47.2, C48.2, D28.C, D29.C, D30.2, J31.1, J32.1, J33.GND, J33.GND2, J34.25, J36.1, R81.1, R83.1, R88.1, R89.1, R90.1, R91.2, R93.1, S11.3, S11.4, U21.2, U22.2, U23.2, U23.PAD, U24.A1, U24.A2, U24.A14, U24.A15, U24.B14, U24.B15, U24.C3, U24.C4, U24.C5, U24.C6, U24.C7, U24.C8, U24.C9, U24.C10, U24.C11, U24.C12, U24.C13, U24.C14, U24.C15, U24.D3, U24.D4, U24.D5, U24.D6, U24.D7, U24.D8, U24.D9, U24.D10, U24.D11, U24.D12, U24.D13, U24.D14, U24.D15, U24.E1, U24.E2, U24.E3, U24.E4, U24.E5, U24.E6, U24.E7, U24.E8, U24.E9, U24.E10, U24.E11, U24.E12, U24.E13, U24.E14, U24.E15, U24.F2, U24.F3, U24.F4, U24.F5, U24.F6, U24.F7, U24.F8, U24.F9, U24.F10, U24.F11, U24.F12, U24.F13, U24.F14, U24.F15, U24.G1, U24.G2, U24.G3, U24.G4, U24.G5, U24.G6, U24.G7, U24.G8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
GND6: C49.2, C50.2, C51.2, C52.2, C53.2, C54.2, C55.2, C56.2, D33.C, D34.C, D35.2, J37.1, J38.1, J39.GND, J39.GND2, J40.25, J42.1, R97.1, R99.1, R104.1, R105.1, R106.1, R107.2, R109.1, S13.3, S13.4, U25.2, U26.2, U27.2, U27.PAD, U28.A1, U28.A2, U28.A14, U28.A15, U28.B14, U28.B15, U28.C3, U28.C4, U28.C5, U28.C6, U28.C7, U28.C8, U28.C9, U28.C10, U28.C11, U28.C12, U28.C13, U28.C14, U28.C15, U28.D3, U28.D4, U28.D5, U28.D6, U28.D7, U28.D8, U28.D9, U28.D10, U28.D11, U28.D12, U28.D13, U28.D14, U28.D15, U28.E1, U28.E2, U28.E3, U28.E4, U28.E5, U28.E6, U28.E7, U28.E8, U28.E9, U28.E10, U28.E11, U28.E12, U28.E13, U28.E14, U28.E15, U28.F2, U28.F3, U28.F4, U28.F5, U28.F6, U28.F7, U28.F8, U28.F9, U28.F10, U28.F11, U28.F12, U28.F13, U28.F14, U28.F15, U28.G1, U28.G2, U28.G3, U28.G4, U28.G5, U28.G6, U28.G7, U28.G8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
GND7: C57.2, C58.2, C59.2, C60.2, C61.2, C62.2, C63.2, C64.2, D38.C, D39.C, D40.2, J43.1, J44.1, J45.GND, J45.GND2, J46.25, J48.1, R113.1, R115.1, R120.1, R121.1, R122.1, R123.2, R125.1, S15.3, S15.4, U29.2, U30.2, U31.2, U31.PAD, U32.A1, U32.A2, U32.A14, U32.A15, U32.B14, U32.B15, U32.C3, U32.C4, U32.C5, U32.C6, U32.C7, U32.C8, U32.C9, U32.C10, U32.C11, U32.C12, U32.C13, U32.C14, U32.C15, U32.D3, U32.D4, U32.D5, U32.D6, U32.D7, U32.D8, U32.D9, U32.D10, U32.D11, U32.D12, U32.D13, U32.D14, U32.D15, U32.E1, U32.E2, U32.E3, U32.E4, U32.E5, U32.E6, U32.E7, U32.E8, U32.E9, U32.E10, U32.E11, U32.E12, U32.E13, U32.E14, U32.E15, U32.F2, U32.F3, U32.F4, U32.F5, U32.F6, U32.F7, U32.F8, U32.F9, U32.F10, U32.F11, U32.F12, U32.F13, U32.F14, U32.F15, U32.G1, U32.G2, U32.G3, U32.G4, U32.G5, U32.G6, U32.G7, U32.G8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
GND8: C65.2, C66.2, C67.2, C68.2, C69.2, C70.2, C71.2, C72.2, D43.C, D44.C, D45.2, J49.1, J50.1, J51.GND, J51.GND2, J52.25, J54.1, R129.1, R131.1, R136.1, R137.1, R138.1, R139.2, R141.1, S17.3, S17.4, U33.2, U34.2, U35.2, U35.PAD, U36.A1, U36.A2, U36.A14, U36.A15, U36.B14, U36.B15, U36.C3, U36.C4, U36.C5, U36.C6, U36.C7, U36.C8, U36.C9, U36.C10, U36.C11, U36.C12, U36.C13, U36.C14, U36.C15, U36.D3, U36.D4, U36.D5, U36.D6, U36.D7, U36.D8, U36.D9, U36.D10, U36.D11, U36.D12, U36.D13, U36.D14, U36.D15, U36.E1, U36.E2, U36.E3, U36.E4, U36.E5, U36.E6, U36.E7, U36.E8, U36.E9, U36.E10, U36.E11, U36.E12, U36.E13, U36.E14, U36.E15, U36.F2, U36.F3, U36.F4, U36.F5, U36.F6, U36.F7, U36.F8, U36.F9, U36.F10, U36.F11, U36.F12, U36.F13, U36.F14, U36.F15, U36.G1, U36.G2, U36.G3, U36.G4, U36.G5, U36.G6, U36.G7, U36.G8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
GND9: C73.2, C74.2, C75.2, C76.2, C77.2, C78.2, C79.2, C80.2, D48.C, D49.C, D50.2, J55.1, J56.1, J57.GND, J57.GND2, J58.25, J60.1, R145.1, R147.1, R152.1, R153.1, R154.1, R155.2, R157.1, S19.3, S19.4, U37.2, U38.2, U39.2, U39.PAD, U40.A1, U40.A2, U40.A14, U40.A15, U40.B14, U40.B15, U40.C3, U40.C4, U40.C5, U40.C6, U40.C7, U40.C8, U40.C9, U40.C10, U40.C11, U40.C12, U40.C13, U40.C14, U40.C15, U40.D3, U40.D4, U40.D5, U40.D6, U40.D7, U40.D8, U40.D9, U40.D10, U40.D11, U40.D12, U40.D13, U40.D14, U40.D15, U40.E1, U40.E2, U40.E3, U40.E4, U40.E5, U40.E6, U40.E7, U40.E8, U40.E9, U40.E10, U40.E11, U40.E12, U40.E13, U40.E14, U40.E15, U40.F2, U40.F3, U40.F4, U40.F5, U40.F6, U40.F7, U40.F8, U40.F9, U40.F10, U40.F11, U40.F12, U40.F13, U40.F14, U40.F15, U40.G1, U40.G2, U40.G3, U40.G4, U40.G5, U40.G6, U40.G7, U40.G8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
LP_UART_RXD: J1.15, U1.B13
LP_UART_RXD1: J10.15, U8.B13
LP_UART_RXD2: J16.15, U12.B13
LP_UART_RXD3: J22.15, U16.B13
LP_UART_RXD4: J28.15, U20.B13
LP_UART_RXD5: J34.15, U24.B13
LP_UART_RXD6: J40.15, U28.B13
LP_UART_RXD7: J46.15, U32.B13
LP_UART_RXD8: J52.15, U36.B13
LP_UART_RXD9: J58.15, U40.B13
LP_UART_TXD: J1.14, U1.A13
LP_UART_TXD1: J10.14, U8.A13
LP_UART_TXD2: J16.14, U12.A13
LP_UART_TXD3: J22.14, U16.A13
LP_UART_TXD4: J28.14, U20.A13
LP_UART_TXD5: J34.14, U24.A13
LP_UART_TXD6: J40.14, U28.A13
LP_UART_TXD7: J46.14, U32.A13
LP_UART_TXD8: J52.14, U36.A13
LP_UART_TXD9: J58.14, U40.A13
unnamed: R1.2, U2.9
unnamed: D3.A, R4.2
unnamed: Q2.5, R17.2
unnamed: R5.1, R9.2, U2.8
unnamed: Q2.2, R18.2
unnamed: JP1.1, Q2.3
unnamed: Q1.1, R10.2
unnamed: R15.2, S2.3, S2.4
unnamed: CHG.2, U4.5
unnamed: JP2.1, Q2.6
unnamed: CHG.1, R13.1
unnamed: LED.2, R2.1
unnamed: CHG.3, R6.2
unnamed: D4.A, R2.2
unnamed: D6.6, U2.3
unnamed: D6.1, J5.A6, J5.B6
unnamed: D1.A, R3.2
unnamed: D6.4, U2.4
unnamed: D6.3, J5.A7, J5.B7
unnamed: D7.A, R16.2
unnamed: R20.2, U7.9
unnamed: D8.A, R21.2
unnamed: R23.1, R24.2, U7.8
unnamed: CHG1.2, U5.5
unnamed: CHG1.1, R27.1
unnamed: CHG1.3, R19.2
unnamed: Q3.1, R28.2
unnamed: R29.2, S4.3, S4.4
unnamed: Q4.5, R30.2
unnamed: Q4.2, R31.2
unnamed: LED1.2, R32.1
unnamed: D9.A, R32.2
unnamed: D10.6, U7.3
unnamed: D10.1, J9.A6, J9.B6
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

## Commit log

2022-02-25 Module device created in temp library
2022-03-30 layout starting - bare minimum
    [SparkFun_AzureWave_Module_Thing_Plus_AW-CU488.brd, SparkFun_AzureWave_Module_Thing_Plus_AW-CU488.sch]
2022-03-30 vbat meas connection and some net cleanup
    [SparkFun_AzureWave_Module_Thing_Plus_AW-CU488.brd, SparkFun_AzureWave_Module_Thing_Plus_AW-CU488.sch]
2022-04-11 layout almost there
    [SparkFun_AzureWave_Module_Thing_Plus_AW-CU488.brd, SparkFun_AzureWave_Module_Thing_Plus_AW-CU488.sch]
2022-04-12 Layout done for proto v01
    [SparkFun_AzureWave_Module_Thing_Plus_AW-CU488.brd, SparkFun_AzureWave_Module_Thing_Plus_AW-CU488.sch]
2022-05-03 tweaking for pin functions in progress
    [SparkFun_AzureWave_Module_Thing_Plus_AW-CU488.brd, SparkFun_AzureWave_Module_Thing_Plus_AW-CU488.sch]
2022-05-04 Routed but needs cleanup and silk updates
    -added auto-reset back in
    -broke out extra GPIO to "bonus" PTH headers on upper sides
    [SparkFun_AzureWave_Module_Thing_Plus_AW-CU488.brd, SparkFun_AzureWave_Module_Thing_Plus_AW-CU488.sch]
2022-05-04 More Layout work - pretty much 99% done
    [SparkFun_AzureWave_Module_Thing_Plus_AW-CU488.brd, SparkFun_AzureWave_Module_Thing_Plus_AW-CU488.sch]
2022-05-05 pre-design review notes and fixes
    -power symbols, Q1, U3, U4 updated to latest libraries
    -consolidated all low current signals to 10mils vias. V_USB (x4), 3.3V (x3), VIN (x2) are still 15mil for higher current capabilities.
    -Center anchor for section text in sch
    -added via near transitioning digital signals near PB26/PB28 PTH headers
    -moved R15 about 20mil to the right to give more room for rework/give more room for the JST connector
    -reduced paste on modules pads by 2mils on either side (for a reduction total on the diameter of the paste hole of 4 mils).
    [SparkFun_AzureWave_Module_Thing_Plus_AW-CU488.brd, SparkFun_AzureWave_Module_Thing_Plus_AW-CU488.sch]
2022-05-05 added USB Shield GND jumper
    -added "shield" net polygons (and via) to connect all 8 shield pads. And add a little extra strength.
    -added jumper to connect USB-C shield to GND (normally closed via trace).
    -moved OSHW logo and version text.
    [SparkFun_AzureWave_Module_Thing_Plus_AW-CU488.brd, SparkFun_AzureWave_Module_Thing_Plus_AW-CU488.sch]
2022-05-06 group review mods
    -add power LED and jumper
    -fixed "connected" typo in sch
    -add ESD protection on D+/D- lines
    -added more vias for power lines (every part of the stream from VUSB to 3.3V to the module).
    -added GND vias under module
    -broke out PB3/A6/SWD_CLK to extra upper side PTH header
    -Broke out PA28 to test point in case I want to test on protos
    -Moved a lot of digital lines under the module to allow more spacing and GND to flow in between them when it could.
    -updated measures
    [SparkFun_AzureWave_Module_Thing_Plus_AW-CU488.brd, SparkFun_AzureWave_Module_Thing_Plus_AW-CU488.sch]
2022-05-06 Module prod ID
    [SparkFun_AzureWave_Module_Thing_Plus_AW-CU488.brd, SparkFun_AzureWave_Module_Thing_Plus_AW-CU488.sch]
2022-05-06 made symbol pin name for download active low
    [SparkFun_AzureWave_Module_Thing_Plus_AW-CU488.sch]
2022-05-06 final check finds
    -Scooted VIN trace for GND flow near Vreg
    -nudged trace off of PA27 to avoid acid trap
    -updated pin names to include SWD functions in symbol
    [SparkFun_AzureWave_Module_Thing_Plus_AW-CU488.brd, SparkFun_AzureWave_Module_Thing_Plus_AW-CU488.sch]
2022-05-06 prototype panel production files (brd and gerbers)
    [SparkFun_AzureWave_Module_Thing_Plus_AW-CU488-Panel.brd]
2022-05-19 Re-routed traces off of charge current select jumper
    -The traces were unnecessarily tight off the jumpers and easy to cut on accident. Now they have more clearance.
    -Also bumped version to v10 in brd and sch
    [SparkFun_AzureWave_Module_Thing_Plus_AW-CU488.brd, SparkFun_AzureWave_Module_Thing_Plus_AW-CU488.sch]
2022-06-13 changes found during proto testing
    -removed R14 pulldown on reset button. It now pulls down directly to GND when pressed.
    -adjusted Charge LED resistor to lower brightness (R3 changed from 1K to 4.7K)
    -Added PTH header breakouts for UART LOG RX and TX.
    -Changed silk on all pins to more user-friendly/common digital numbers.
    -Added jumpers to more easily remove auto-boot circuit if needed for advanced use cases
    [SparkFun_AzureWave_Module_Thing_Plus_AW-CU488.brd, SparkFun_AzureWave_Module_Thing_Plus_AW-CU488.sch]
2022-06-13 centered SFE logo and product name text
    [SparkFun_AzureWave_Module_Thing_Plus_AW-CU488.brd, SparkFun_AzureWave_Module_Thing_Plus_AW-CU488.sch]
2022-06-14 Reds review catches
    -added note in SCH about pwr LED jumper
    -approved jumper overlap DRC errors
    -added table lines to schematic info about auto-reset
    -moved OSHW logo over via
    -removed unncessary GND vias under USB-C
    [SparkFun_AzureWave_Module_Thing_Plus_AW-CU488.brd, SparkFun_AzureWave_Module_Thing_Plus_AW-CU488.sch]
2022-06-14 more changes from reds review
    -auto-reset disable jumpers changed to JP1 and JP2
    -added more measures to top pht header on header rows
    -swapped vreg from ap2112 to XC6222
    -Add SFE LOGO to bottom silk
    -more gnd vias near potential gnd loops
    -fixed acid traps
    [SparkFun_AzureWave_Module_Thing_Plus_AW-CU488.brd, SparkFun_AzureWave_Module_Thing_Plus_AW-CU488.sch]
2022-06-14 AW-CU488 library work
    -removed NC pin
    -took "$" out of part name attribute
    [SparkFun_AzureWave_Module_Thing_Plus_AW-CU488.brd, SparkFun_AzureWave_Module_Thing_Plus_AW-CU488.sch]
2022-06-14 RED power LED limiting resistor reduced to 1K for better brightness matching
    [SparkFun_AzureWave_Module_Thing_Plus_AW-CU488.brd, SparkFun_AzureWave_Module_Thing_Plus_AW-CU488.sch]
2022-06-15 Blue LED resistor (R4) corrected to 4.7K
    also updated Prod_ID on xc6222 vreg
    [SparkFun_AzureWave_Module_Thing_Plus_AW-CU488.brd, SparkFun_AzureWave_Module_Thing_Plus_AW-CU488.sch]
2022-06-16 Production Panel BRD and Gerbers v10
    [SparkFun_AzureWave_Module_Thing_Plus_AW-CU488-Panel.brd, SparkFun_AzureWave_Module_Thing_Plus_AW-CU488-Panel_b.brd]
2022-06-29 added arduino pin mapping table to schematic
    [SparkFun_AzureWave_Module_Thing_Plus_AW-CU488.sch]
2022-07-13 Added SPI1 pin-names to device symbol in schematic
    [SparkFun_AzureWave_Module_Thing_Plus_AW-CU488.sch]
2022-07-13 audio codec specific pin-names into sch symbol
    [SparkFun_AzureWave_Module_Thing_Plus_AW-CU488.sch]
2022-07-28 Dimensional drawings and schematic PDF

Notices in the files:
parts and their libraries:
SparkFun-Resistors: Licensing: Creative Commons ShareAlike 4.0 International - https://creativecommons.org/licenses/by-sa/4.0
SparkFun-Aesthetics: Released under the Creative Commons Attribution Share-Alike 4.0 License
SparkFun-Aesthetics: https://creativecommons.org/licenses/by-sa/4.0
